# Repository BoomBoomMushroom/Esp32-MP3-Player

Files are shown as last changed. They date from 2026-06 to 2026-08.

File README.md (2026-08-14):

# ESP32 MP3 Player
An MP3 Player powered by an ESP32, with both bluetooth and a speaker output

I made this project because I want to move away from Spotify and own the songs I play. I have bought a dozen or two songs from bandcamp and that will be whats played on this!

687474~1



Video of it working (Nothing here yet, still need funding)

Features:
- Seeed studio ESP32-S3 plus for the MCU and battery charging circuit
- A 2.8in ili9341 tft color screen
- MAX17048G+T10 for battery level checking
- a rotary encoder for input, and a vol up and vol down button
- MAX98357A + 8ohm 3W speakers for use w/o bluetooth headphones/speakers
- Any single cell LiPo works, im probably going to use a 2000mAh or 3000mAh battery

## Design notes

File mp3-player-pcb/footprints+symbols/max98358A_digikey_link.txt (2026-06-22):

https://www.digikey.com/en/products/detail/analog-devices-inc-maxim-integrated/MAX98357AETE-T/4936122

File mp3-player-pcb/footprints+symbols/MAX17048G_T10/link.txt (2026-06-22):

https://www.digikey.com/en/products/detail/analog-devices-inc-maxim-integrated/MAX17048G-T10/3758921

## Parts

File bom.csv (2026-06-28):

Name | Extended Price | Quantity Used | Link
PCB | 2 | 1 | JLC PCB
Seeed Studio Xiao ESP32 S3 Plus | 7.99 | 1 | https://www.seeedstudio.com/Seeed-Studio-XIAO-ESP32S3-Plus-p-6361.html
2.8in SPI TFT Color Screen | 6.06 | 1 | https://www.aliexpress.us/item/3256805941534896.html
0805 SMD Ferrite Bead : 600ohm @ 100MHz | 0.55 | 1 | https://www.lcsc.com/product-detail/C2441364.html
Rotary Encoder | 2.12 | 1 | https://www.lcsc.com/product-detail/C18164805.html
Right Angle THT Tactile Switch | 1.87 | 2 | https://www.lcsc.com/product-detail/C266196.html
Audio Amplifier MAX98357AETE+T | 1.33 | 1 | https://www.lcsc.com/product-detail/C910544.html
Battery Monitor IC MAX17048G+T10 | 2.04 | 1 | https://www.lcsc.com/product-detail/C2682616.html
AO3407A MOSFET | 0.49 | 1 | https://www.lcsc.com/product-detail/C15155.html
0603 SMD 0.1uF Cap | 1.42 | 3 | https://www.lcsc.com/product-detail/C1591.html
0603 SMD 10uF Cap | 1.31 | 3 | https://www.lcsc.com/product-detail/C1691.html
Electrolytic THT 0.1uF Cap | 0.64 | 1 | https://www.lcsc.com/product-detail/C45664.html
Electrolytic THT 100uF Cap | 0.49 | 2 | https://www.lcsc.com/product-detail/C271443.html
100kohm Resistor THT | 0.66 | 3 | https://www.lcsc.com/product-detail/C172965.html
10kohm Resistor THT | 0.69 | 2 | https://www.lcsc.com/product-detail/C2903232.html
100ohm Resistor THT | 0.74 | 1 | https://www.lcsc.com/product-detail/C2903232.html
4.7kohm Resistor THT | 0.79 | 2 | https://www.lcsc.com/product-detail/C433513.html
Transparent PETG Filament | 15.99 | 1 | https://www.microcenter.com/product/626540/inland-175mm-petg-3d-printer-filament-1kg-(22-lbs)-spool-clear
Aliexpress shipping and stuff total | 8.05 | -1 | null
JLC PCB shipping and stuff total | 5.30 | -1 | null
LCSC shipping and stuff total | 27.05 | -1 | null
Seeed Studio shipping and stuff total | 15.30 | -1 | null
Total w/ shipping | ~71.69 | -1 | null

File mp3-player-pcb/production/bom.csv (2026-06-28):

Designator | Footprint | Quantity | Value | LCSC Part #
_2, |  | 2
BT1 | JST_EH_B2B-EH-A_1x02_P2.50mm_Vertical | 1 | Battery
C1 | CP_Radial_D4.0mm_P2.00mm | 1 | 0.1uF
C10, C8 | CP_Radial_D4.0mm_P2.00mm | 2 | 100uF
C2, C5, C7 | 0603 | 3 | 0.1uF
C3, C4, C6 | 0603 | 3 | 10uF
FB1 | 0805 | 1 | FerriteBead
LS1 | PinHeader_1x02_P2.54mm_Vertical | 1 | Speaker
R1, R2, R3 | R_Axial_DIN0204_L3.6mm_D1.6mm_P5.08mm_Horizontal | 3 | 100kOhm
R4 | R_Axial_DIN0204_L3.6mm_D1.6mm_P5.08mm_Horizontal | 1 | 100 ohm
R5, R6 | R_Axial_DIN0204_L3.6mm_D1.6mm_P5.08mm_Horizontal | 2 | 10kohm
R7, R8 | R_Axial_DIN0204_L3.6mm_D1.6mm_P5.08mm_Horizontal | 2 | 4.7k
SW1 | RotaryEncoder_Bourns_Vertical_PEC12R-3x17F-Sxxxx | 1 | RotaryEncoder_Switch
SW2 | SW_Tactile_SPST_Angled_PTS645Vx58-2LFS | 1 | Volume Up
SW3 | SW_Tactile_SPST_Angled_PTS645Vx58-2LFS | 1 | Volume Down
TP1 | TestPoint_Pad_D1.5mm | 1 | D-
TP2 | TestPoint_Pad_D1.5mm | 1 | D+
U1 | XIAO-ESP32-S3-Plus-SMD | 1 | XIAO-ESP32-S3-Plus-SMD
U2 | SOT-23-3L_AOS | 1 | AO3407A
U3 | 21-0168E_T822-3_MXM | 1 | MAX17048G+T10
U4 | TQFN-16-1EP_3x3mm_P0.5mm_EP1.23x1.23mm | 1 | MAX98357A
U5 | CR2013-MI2120 | 1 | CR2013-MI2120

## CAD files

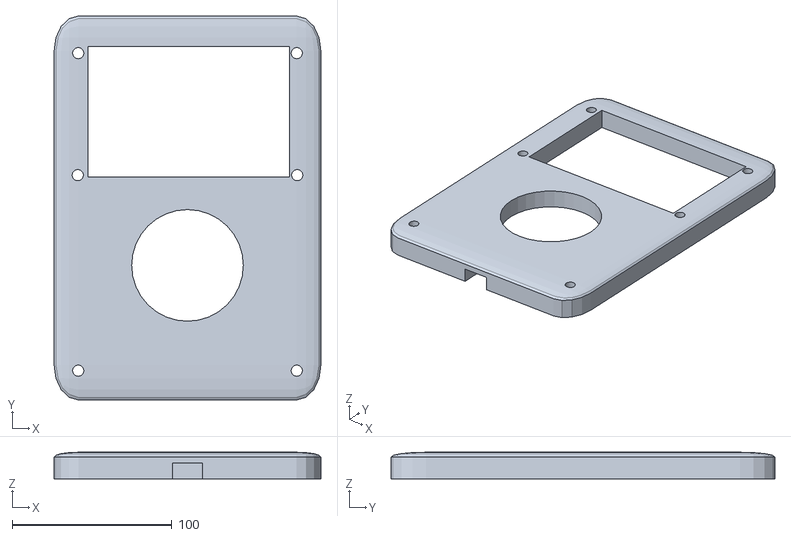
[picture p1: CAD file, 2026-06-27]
cad/case_top.stl
167.3 x 240.7 x 16.7

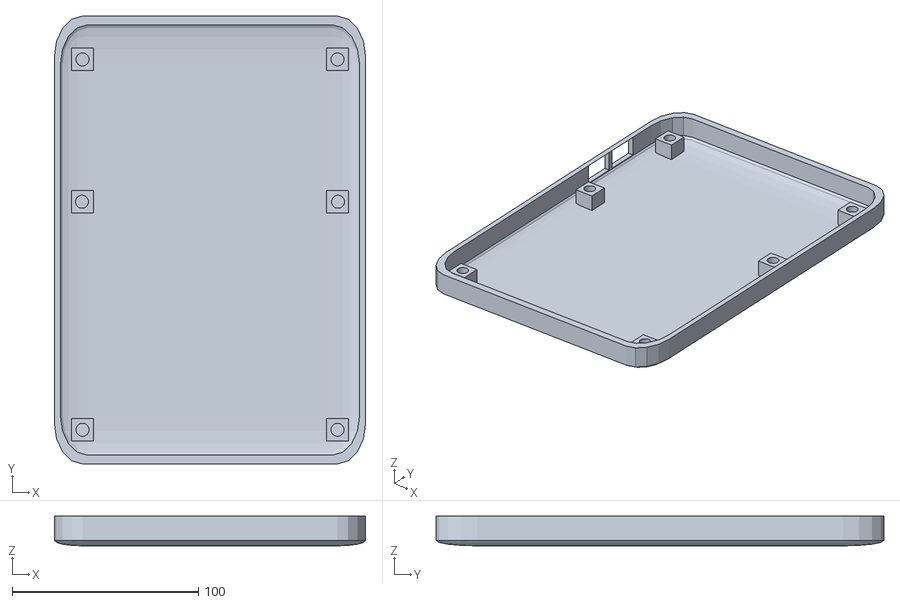
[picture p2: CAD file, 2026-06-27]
cad/case_bottom.stl
167.3 x 240.7 x 16.0

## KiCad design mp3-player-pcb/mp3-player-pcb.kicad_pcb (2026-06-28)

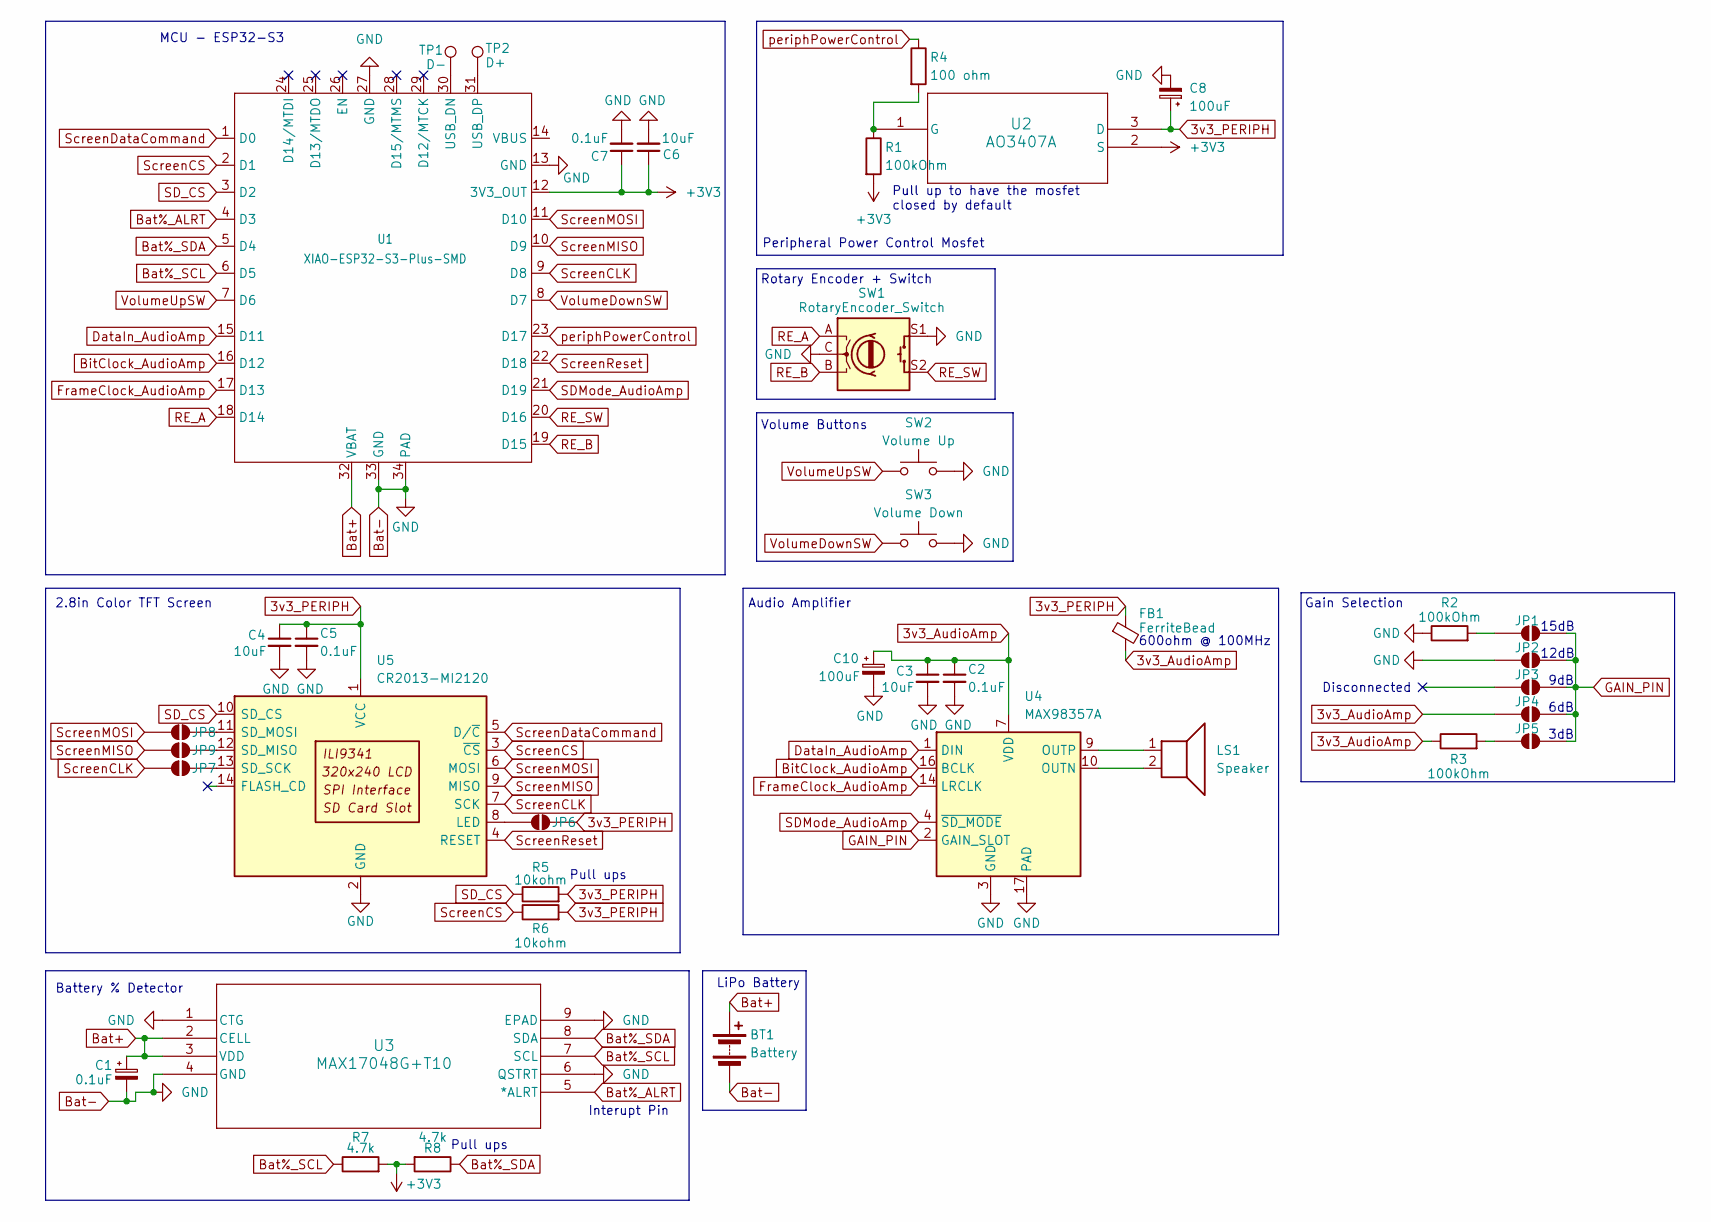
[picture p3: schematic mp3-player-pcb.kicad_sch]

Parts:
BT1: Battery; JST_EH_B2B-EH-A_1x02_P2.50mm_Vertical
C1: 0.1uF; CP_Radial_D4.0mm_P2.00mm
C2, C5, C7: 0.1uF; C_0603_1608Metric_Pad1.08x0.95mm_HandSolder
C3, C4, C6: 10uF; C_0603_1608Metric_Pad1.08x0.95mm_HandSolder
C8, C10: 100uF; CP_Radial_D4.0mm_P2.00mm
FB1: FerriteBead; C_0805_2012Metric_Pad1.18x1.45mm_HandSolder
JP1, JP2, JP3, JP4, JP5, JP6, JP7, JP8, JP9: SolderJumper_2_Open; SolderJumper-2_P1.3mm_Open_Pad1.0x1.5mm
LS1: Speaker; PinHeader_1x02_P2.54mm_Vertical
R1, R2, R3: 100kOhm; R_Axial_DIN0204_L3.6mm_D1.6mm_P5.08mm_Horizontal
R4: 100 ohm; R_Axial_DIN0204_L3.6mm_D1.6mm_P5.08mm_Horizontal
R5, R6: 10kohm; R_Axial_DIN0204_L3.6mm_D1.6mm_P5.08mm_Horizontal
R7, R8: 4.7k; R_Axial_DIN0204_L3.6mm_D1.6mm_P5.08mm_Horizontal
SW1: RotaryEncoder_Switch; RotaryEncoder_Bourns_Vertical_PEC12R-3x17F-Sxxxx
SW2: Volume Up; SW_Tactile_SPST_Angled_PTS645Vx58-2LFS
SW3: Volume Down; SW_Tactile_SPST_Angled_PTS645Vx58-2LFS
TP1: D-; TestPoint_Pad_D1.5mm
TP2: D+; TestPoint_Pad_D1.5mm
U1: XIAO-ESP32-S3-Plus-SMD
U2: AO3407A; SOT-23-3L_AOS
U3: MAX17048G+T10; 21-0168E_T822-3_MXM
U4: MAX98357A; TQFN-16-1EP_3x3mm_P0.5mm_EP1.23x1.23mm
U5: CR2013-MI2120

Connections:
3v3_AudioAmp: C2.1, C3.1, C10.1, FB1.2, JP4.1 (A), R3.1, U4.7 (VDD), U4.8 (VDD)
3v3_PERIPH: C4.1, C5.1, C8.1, FB1.1, JP6.2 (B), R5.2, R6.2, U2.3 (D), U5.1 (VCC)
+3V3: C6.1, C7.1, R1.2, R7.2, R8.2, U1.12 (3V3_OUT), U2.2 (S)
Bat%_ALRT: U1.4 (D3), U3.5 (*ALRT)
Bat%_SCL: R7.1, U1.6 (D5), U3.7 (SCL)
Bat%_SDA: R8.1, U1.5 (D4), U3.8 (SDA)
Bat+: BT1.1 (+), C1.1, U1.32 (VBAT), U3.2 (CELL), U3.3 (VDD)
Bat-: BT1.2 (-), C1.2, C2.2, C3.2, C4.2, C5.2, C6.2, C7.2, C8.2, C10.2, JP2.1 (A), R2.1, SW1.C, SW1.S1, SW2.2, SW3.2, U1.13 (GND), U1.27 (GND), U1.33 (GND), U1.34 (PAD), U3.1 (CTG), U3.4 (GND), U3.6 (QSTRT), U3.9 (EPAD), U4.3 (GND), U4.11 (GND), U4.15 (GND), U4.17 (PAD), U5.2 (GND)
BitClock_AudioAmp: U1.16 (D12), U4.16 (BCLK)
DataIn_AudioAmp: U1.15 (D11), U4.1 (DIN)
FrameClock_AudioAmp: U1.17 (D13), U4.14 (LRCLK)
GAIN_PIN: JP1.2 (B), JP2.2 (B), JP3.2 (B_2), JP4.2 (B), JP5.2 (B), U4.2 (GAIN_SLOT)
unnamed: JP1.1 (A), R2.2
unnamed: JP5.1 (A), R3.2
unnamed: JP6.1 (A), U5.8 (LED)
unnamed: JP7.2 (B), U5.13 (SD_SCK)
unnamed: JP8.2 (B), U5.11 (SD_MOSI)
unnamed: JP9.2 (B), U5.12 (SD_MISO)
unnamed: TP1.1 (1_1), U1.30 (USB_DN)
unnamed: TP2.1 (1_1), U1.31 (USB_DP)
unnamed: R1.1, R4.2, U2.1 (G)
unnamed: LS1.2, U4.10 (OUTN)
unnamed: LS1.1, U4.9 (OUTP)
RE_A: SW1.A, U1.18 (D14)
RE_B: SW1.B, U1.19 (D15)
RE_SW: SW1.S2, U1.20 (D16)
SDMode_AudioAmp: U1.21 (D19), U4.4 (~SD_MODE)
SD_CS: R5.1, U1.3 (D2), U5.10 (SD_CS)
ScreenCLK: JP7.1 (A), U1.9 (D8), U5.7 (SCK)
ScreenCS: R6.1, U1.2 (D1), U5.3 (~CS)
ScreenDataCommand: U1.1 (D0), U5.5 (D/~C)
ScreenMISO: JP9.1 (A), U1.10 (D9), U5.9 (MISO)
ScreenMOSI: JP8.1 (A), U1.11 (D10), U5.6 (MOSI)
ScreenReset: U1.22 (D18), U5.4 (RESET)
VolumeDownSW: SW3.1, U1.8 (D7)
VolumeUpSW: SW2.1, U1.7 (D6)
periphPowerControl: R4.1, U1.23 (D17)

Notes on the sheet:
Pull up to have the mosfet closed by default
600ohm @ 100MHz
2.8in Color TFT Screen
Volume Buttons
Rotary Encoder + Switch
6dB
Battery % Detector
Audio Amplifier
9dB
12dB
MCU - ESP32-S3
3dB
Gain Selection
Disconnected
Interupt Pin
Pull ups
LiPo Battery
15dB
Peripheral Power Control Mosfet

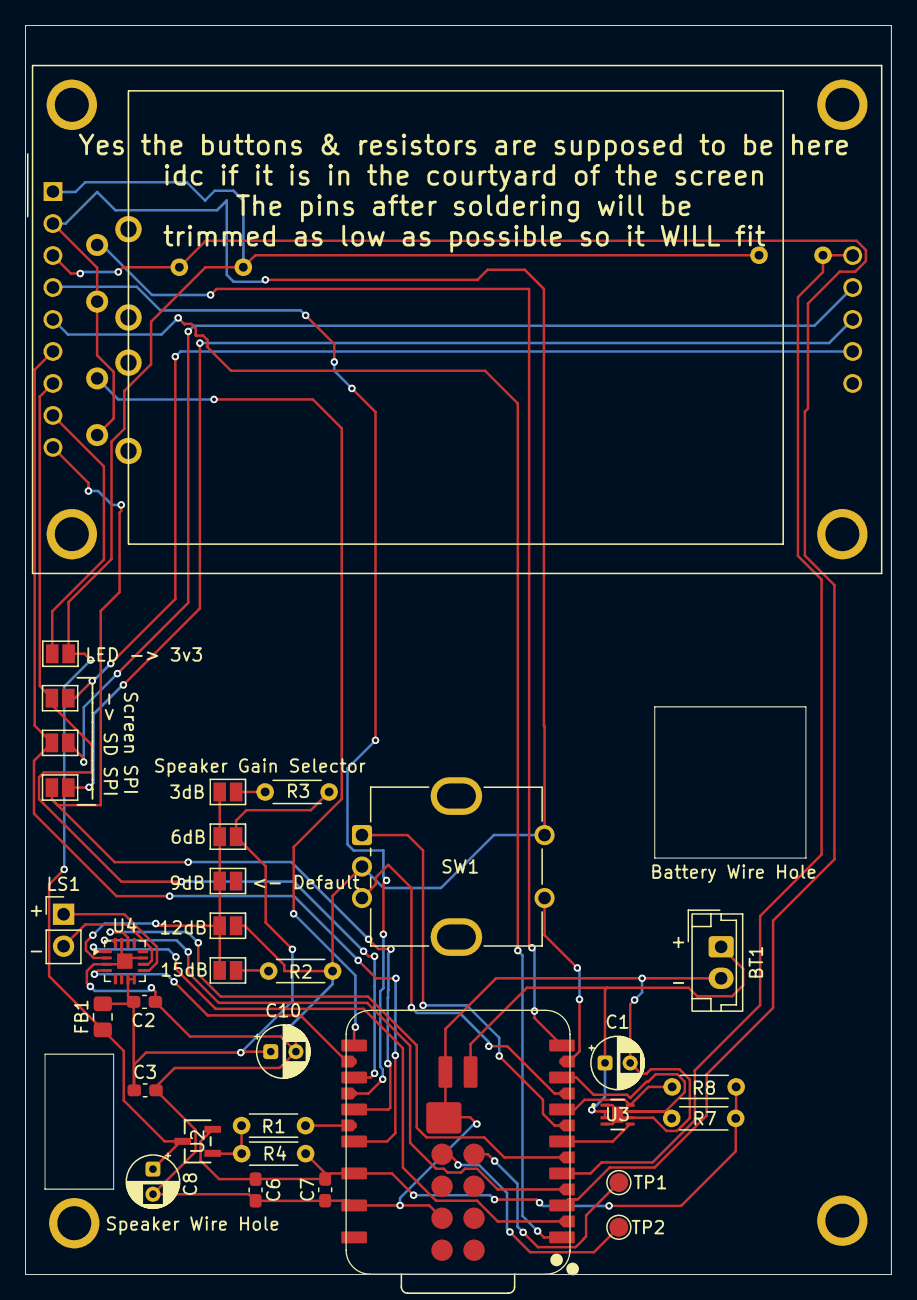
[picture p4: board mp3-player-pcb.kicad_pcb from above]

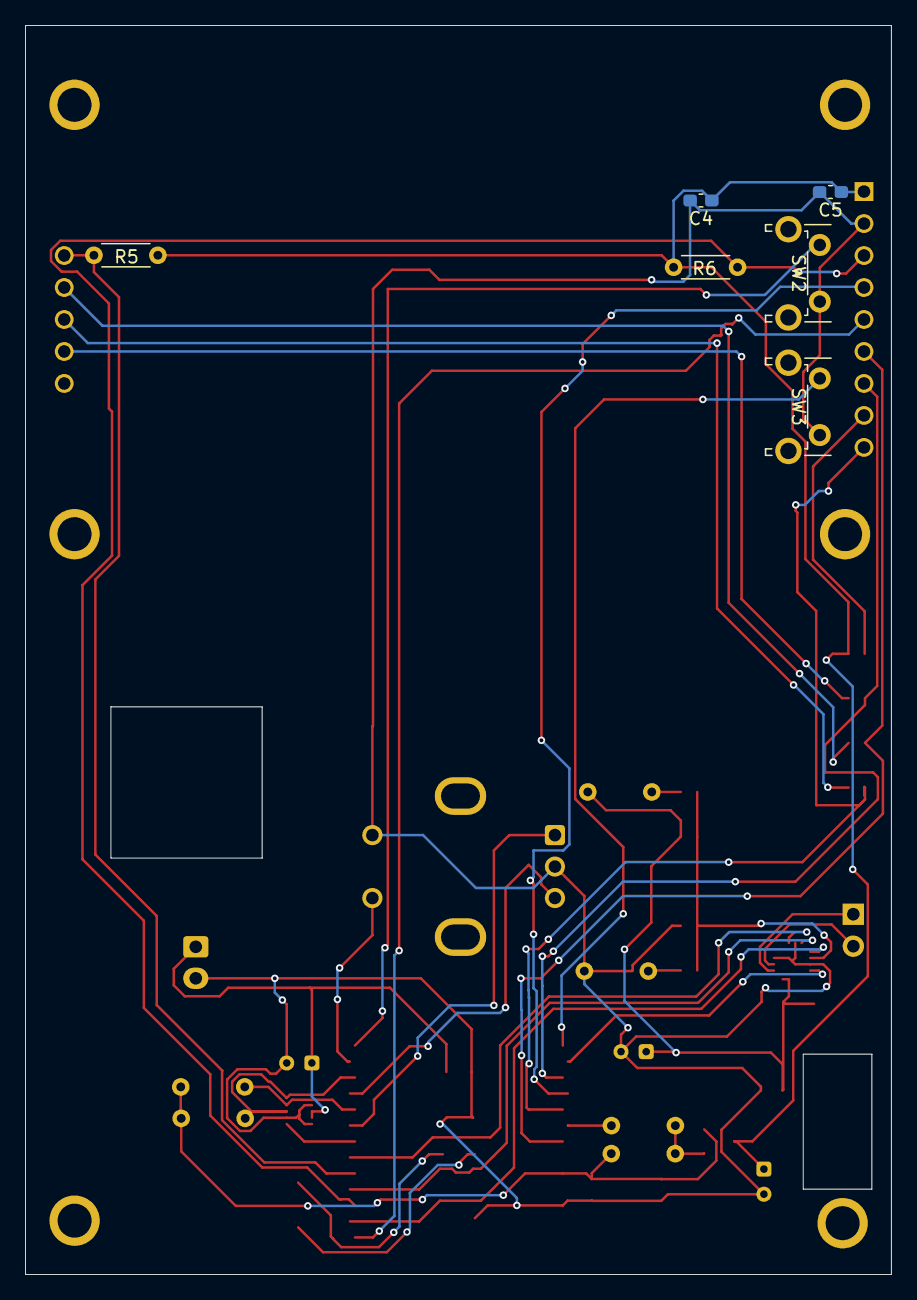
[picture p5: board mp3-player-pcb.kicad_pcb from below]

Board: 2 copper layers, 68.8 x 99.2 mm, 39 parts (6 on the bottom side), 37 nets.

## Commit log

2026-06-22 feat: schematic done and pcb layout finished, now have to route traces
    [mp3-player-pcb.kicad_pcb, mp3-player-pcb.kicad_sch]
2026-06-22 feat: finished routing the pcb
    [mp3-player-pcb.kicad_pcb, mp3-player-pcb.kicad_sch]
2026-06-27 feat: made case cad
    [case_bottom.stl, case_top.stl, mp3-player-pcb.kicad_pcb]
2026-06-28 bom and other parts added
    [bom.csv, designators.csv, mp3-player-pcb.kicad_pcb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]
